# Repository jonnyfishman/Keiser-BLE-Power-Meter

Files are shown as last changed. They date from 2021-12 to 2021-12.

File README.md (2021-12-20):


<h3 align="center">BLE Power Meter</h3>

  <p align="center">
    Do you have an exercise bike without bluetooth but would still like to use training platforms like Zwift, Rouvy and Training Peaks? Using the Adafruit Feather nRF52 you can.
    <br />

  </p>
</div>

<!-- TABLE OF CONTENTS -->
<details>
  <summary>Table of Contents</summary>
  <ol>
    <li>
      <a href="#about-the-project">About The Project</a>
    </li>
    <li>
      <a href="#getting-started">Getting Started</a>
      <ul>
        <li><a href="#prerequisites">Bill of Materials</a></li>
        <li><a href="#prerequisites">Wiring</a></li>
        <li><a href="#installation">Installation</a></li>
        <li><a href="#acknowledgments">Acknowledgments</a></li>        
      </ul>
    </li>
    <li><a href="#license">License</a></li>
  </ol>
</details>

<!-- ABOUT THE PROJECT -->
## About The Project

Most older exercise bikes lack modern bluetooth compatibility but do still have a readout of the power generated. Using the Adafruit Feather you can bridge this gap.

This project was designed for the Keiser M3 exercise bike specifically but could be adapted to various others.

Most older exercise bikes use pedal cadence to calculate the power which appears on the head unit. To keep it compact and the design below uses a hall effect sensor and a magnet on the pedal arm to calculate cadence but you could modify the bikes cadence sensor directly as an alternative.

It also uses an MPU6050 on the gear selector to detect changes and adjust the power output. Once calibrated it can be adjusted to replicate the changes in power seen on the exercise bike head unit.

<p align="right">(<a href="#top">back to top</a>)</p>

<!-- GETTING STARTED -->
## Getting Started

### Bill of Materials

* An [Adafruit Feather nRF52](https://www.adafruit.com/product/3406)
* MPU6050
* A low voltage unipolar hall effect sensor
* Lipo battery (optional)

### Wiring

Components are wired as follows.

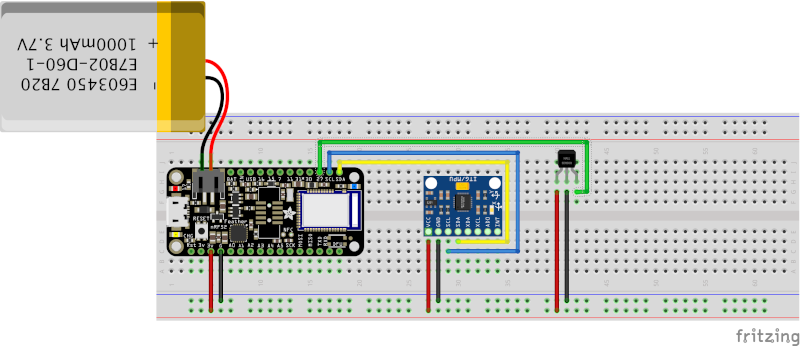
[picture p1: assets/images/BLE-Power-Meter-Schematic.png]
BLE Power Meter Fritzing


This can be soldered compactly as follows. **Notice the horizontal orientation of the MPU6050.**

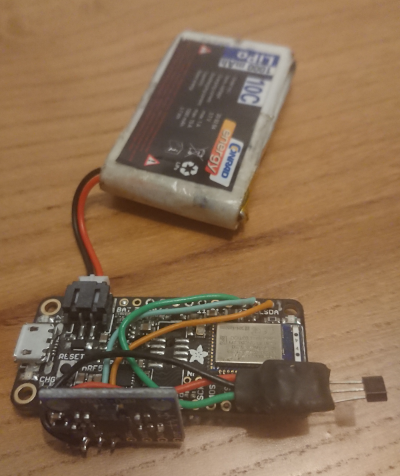
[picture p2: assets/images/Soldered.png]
Soldered Circuit


And temporarily mounted of the Keiser M3 with MPU6050 at the top.

Circuit Mounted

### Installation

1. Follow the instructions on the Adafruit site to connect the nRF52832 to Arduino IDE. [https://learn.adafruit.com/bluefruit-nrf52-feather-learning-guide](https://learn.adafruit.com/bluefruit-nrf52-feather-learning-guide)

2. Clone the repo
   ```sh
   git clone https://github.com/jonnyfishman/Keiser-BLE-Power-Meter.git
   ```
3. Open `BLE_Power/BLE_Power.ino` in the Arduino IDE (if you move the main `.ino` file make sure that all the included `.cpp` and `.h` files are in the same directory)

4. Edit the code if needed.

> By default debugging is disabled. To enable it remove the comments from the start of the file.

```ide
//#define DEBUG  
    BECOMES
#define DEBUG  
```

> Optionally adjust.

```ide
#define CALIBRATE_WAIT_MS   3000          // How long the sensor will initially wait for the low and high set points
#define HALL_EFFECT_SENSOR  27            // Where the hall effect sensor sense pin is connected
#define LED_PIN             LED_RED       // For visual reference using the onboard LED
#define TIMING_ERROR        10            // For the state engine timing. Increase data does not seem to be arriving
```

5. Flash the code to your board.

6. Connect to the training platform of your choice. When powered the device should show up as a power source.

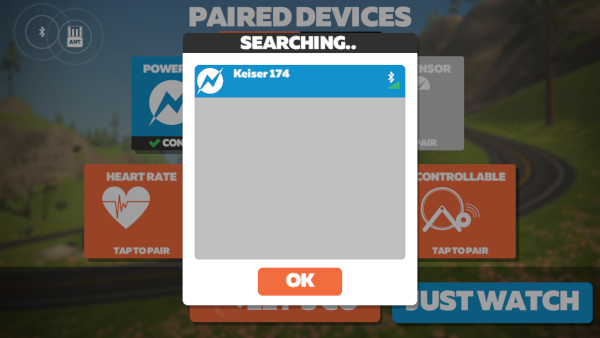
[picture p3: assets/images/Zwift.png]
Zwift Device Selection Screen


<p align="right">(<a href="#top">back to top</a>)</p>

## Roadmap

<ul>
  <li>Add CCCD callback for custom settings to detect if sending is required</li>
  <li>Update app and publish</li>
  <li>Explain gear selection code</li>
  <li>Explain how to map power from other exercise bikes</li>
  <li>Add BLE troubleshooting guide</li>
</ul>

<!-- LICENSE -->
## License

Distributed under the MIT License. See `LICENSE.txt` for more information.

<p align="right">(<a href="#top">back to top</a>)</p>

<!-- ACKNOWLEDGMENTS -->
## Acknowledgments

A lot of the inspiration and help with the bluetooth characteristics comes from Bruno Fernandez-Ruiz's Javascript power meter code. He has various other power meter projects if you are interested.

[https://github.com/olympum/ble-cycling-power](https://github.com/olympum/ble-cycling-power)

<p align="right">(<a href="#top">back to top</a>)</p>

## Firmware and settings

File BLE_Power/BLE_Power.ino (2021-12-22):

//#define DEBUG           
#ifdef DEBUG
  #define DEBUG_PRINT(x)        Serial.print(x)
  #define DEBUG_PRINTLN_HEX(x)  Serial.println(x,HEX)
  #define DEBUG_PRINTLN(x)      Serial.println(x)
#else
  #define DEBUG_PRINT(x)
  #define DEBUG_PRINTLN_HEX(x)
  #define DEBUG_PRINTLN(x) 
#endif 

#define CALIBRATE_WAIT_MS   3000          // How long the sensor will initially wait for the low and high set points
#define HALL_EFFECT_SENSOR  27            // Where the hall effect sensor sense pin is connected
#define LED_PIN             LED_RED       // For visual reference using the onboard LED
#define TIMING_ERROR        10            // For the state engine timing. Increase data does not seem to be arriving

// Main BLE stack
#include <bluefruit.h>

// MPU6050 Power Data
#include "Power.h"
CalculatePower calculatepower;

// Power Meter BLE services
#include "BLEService.h"
SetupGATT setupgatt;
BLENotify blenotify;

// Battery BLE service
#include "BatteryService.h"   
FeatherBattery featherbattery;

// Variables used in main loop
int cadence = 0;
unsigned long tick = 0;
unsigned long last_event_time = 0;
unsigned long total_revolutions = 0;
uint16_t event_time = 0;

void setup() {
  Serial.begin(115200);

  pinMode(HALL_EFFECT_SENSOR, INPUT);               // Setup hall effect sensor to detect cadence
  
  calculatepower.begin();                           // Setup MPU6050

  DEBUG_PRINTLN("\nSet gear max and min values");   // Configure set points
  
    digitalWrite(LED_PIN,HIGH);
    delay(CALIBRATE_WAIT_MS);
    calculatepower.setLowGear();
    digitalWrite(LED_PIN,LOW);
    delay(CALIBRATE_WAIT_MS);
    digitalWrite(LED_PIN,HIGH);
    delay(CALIBRATE_WAIT_MS);
    digitalWrite(LED_PIN,LOW);
    calculatepower.setHighGear();

  while ( !Serial ) delay(10);                      // for nrf52840 with native usb

  DEBUG_PRINTLN("Configuring the Cycle Power Service");
  setupgatt.Config();                             
  setupgatt.CyclePower();                         
  setupgatt.CycleSettings();  
  
  // Setup the advertising packet(s)
  DEBUG_PRINTLN("Setting up the advertising payload(s)");
  setupgatt.Advertising();

  DEBUG_PRINTLN("Advertising!");
}

void loop() {

  if ( setupgatt.get_connected() == true ) {                         // Only send values if the peripheral is connected

          // Get cadence information
          
          if ( digitalRead(HALL_EFFECT_SENSOR) == LOW ) {           // Detect a full revolution

            digitalWrite(LED_PIN,HIGH);                             // Trigger visual for revolution
                               
          unsigned long time_diff = millis() - last_event_time;     // Time difference since last rotation (not event time yet)
          last_event_time = millis();
          
          /* 
           *  time_diff = 1 revolution
           *  time_diff / time_diff = 1 revolution / time_diff                                       (gives revolution / ms)
           *  time_diff / time_diff * 60000 (ms in a minute) = 1 revolution * 60000 / time_diff      (gives rev / min)
           */
          cadence = 60000 / time_diff;  
          
          // Add to cumulative value
          total_revolutions++;                                       

          /*
           *  In spec - Unit is in seconds with a resolution of 1/2048 
           *  so millis is multiplied by 1000 (to get seconds) and divided by 1024
           *  Spec accepts a 16bit value for the time so anything higher than 2^16 (65536) needs to rollover using modulus
           */
          event_time = ( millis() * 1000 / 1024 ) % 65536;  

            // Prevent getting repeated values for the same revolution i.e. if cadence sensor stops in front of the hall effect sensor
            while ( digitalRead(HALL_EFFECT_SENSOR) == LOW ) {    
              delay(5);
              //wait until event finishes
            }
            
            digitalWrite(LED_PIN,LOW);                            // Trigger end of visual
            
                    
          }
          else if ( millis() - last_event_time > 6000 ) {         // Return cadence to zero if the pedalling is stopped for 6 seconds
              cadence = 0;          
          }   // End of digitalRead(HALL_EFFECT_SENSOR) == LOW loop

        /* 
         *  Control the timing of the following events using millis() to detect every half second
         *  If sensor information is being missed then increase the TIMING ERROR
         *  Using old_tick ensure that each block only sends once
         *  If power meter response is sluggish, adjust these values to update the information more often
         */
        unsigned long old_tick = tick;        
        if (millis()%500 <= TIMING_ERROR) {               
          tick++;
        }

        // Send sensor information     
        if ( tick != old_tick && tick%2 == 0 ) {              // Send power data every second half second
            uint16_t power = calculatepower.CadenceToPower(cadence);      // Get power from cadence
            blenotify.CyclePower(power, total_revolutions, event_time );  
            
            DEBUG_PRINT("Cadence: " );DEBUG_PRINT(cadence);DEBUG_PRINT(" Power: " );DEBUG_PRINT(power);DEBUG_PRINT(" Total Revs: ");DEBUG_PRINT(total_revolutions);DEBUG_PRINT(" Event Time: ");DEBUG_PRINTLN(event_time);        
        }
        
        if ( tick != old_tick && tick%2 == 0 ) {                   // Send settings information every second tick i.e. 1s
            calculatepower.update();                  // Update gear and angle            
            uint16_t power = calculatepower.CadenceToPower(cadence);      // Get power from cadence
            int battery_percent = featherbattery.getPercent();            // Get battery value
            blenotify.CycleSettings( calculatepower.getGear(), calculatepower.getAngle(), cadence, battery_percent );
            
            DEBUG_PRINT("Gear: " );DEBUG_PRINT(calculatepower.getGear());DEBUG_PRINT(" Angle: ");DEBUG_PRINT(calculatepower.getAngle());DEBUG_PRINT(" Cadence: ");DEBUG_PRINTLN(cadence);
            
            // Check for a command from the app
            int command = setupgatt.get_command();
              if ( command > 0 ) {
                    
                    switch(command){                                           
                        case 'a': 
                          calculatepower.setLowGear();
                          
                          break;
                        case 'b': 
                          calculatepower.setHighGear();
                          
                          break;                          
                        default:                                                // Assume gear is somehow out of bounds 
                          
                          break;
                        }
                        
                     setupgatt.clear_command();
              }
            } 
            
            if ( tick != old_tick && tick%120 == 0 ) {                  // Send battery value every minute
                int battery_percent = featherbattery.getPercent();            // Get battery value
                blenotify.Battery( battery_percent );
                DEBUG_PRINT("Batery: ");DEBUG_PRINTLN(battery_percent);
            } 
         
          
          
  } // End of setupgatt.get_connected() == true loop
  
} 

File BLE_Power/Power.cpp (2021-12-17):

#include <Arduino.h>
#include "Power.h"

long minVal, maxVal;
float angle;

float X_accel_offset, Y_accel_offset, Z_accel_offset;

extern int gear_threshhold;
extern int gear;

void CalculatePower::begin() {                         
  Wire.begin(); 
  Wire.beginTransmission(MPU6050_ADDR);               // Contact MPU6050
  Wire.write(MPU6050_SIGNAL_PATH_RESET_REGISTER);     // Power management register
  Wire.write(0x01 );                                  // Send reset code
  Wire.endTransmission(false); 
  Wire.write(MPU6050_ACCEL_CONFIG_REGISTER);          // Accel config register
  Wire.write(0x18);                                   // Set range to +-16G to smooth motion somewhat
  Wire.endTransmission(true); 

  this->getOffsets();                                 // Reduce error (https://www.digikey.co.uk/en/articles/using-an-accelerometer-for-inclination-sensing)
}

void CalculatePower::getOffsets() {                         
  float accumulated_raw[3] = {0,0,0};                 
  
  for(int i = 0; i < OFFSET_LOOP; i++){
    this->readRaw();
    accumulated_raw[0] += X_accel;
    accumulated_raw[1] += Y_accel;
    accumulated_raw[2] += Z_accel;
    delay(1);                                         // Short delay to get different values
  }

  // Get average position
  X_accel_offset = X_accel / OFFSET_LOOP;
  Y_accel_offset = Y_accel / OFFSET_LOOP;
  Z_accel_offset = Z_accel / OFFSET_LOOP;
}

int CalculatePower::setGearLimits(int pointer) {                         
  
  int accumulated_angles = 0;                         // This does the same as getOffsets but with the angle 
  
  for(int i = 0; i < LIMIT_LOOP; i++){
    this->update();
    accumulated_angles += angle;
    delay(1); 
  }

  return limits[pointer] = accumulated_angles / LIMIT_LOOP;
}

void CalculatePower::readRaw() {    
  Wire.beginTransmission(MPU6050_ADDR); 
  
  Wire.write(MPU6050_ACCEL_OUT);                      // Start receiving accelerator values
  Wire.endTransmission(false);                        // Send stop message but remain in control
  Wire.requestFrom(MPU6050_ADDR,6,true);              // Request X,Y and Z data 

  int16_t rawData[3];       
  
  for(int i=0;i<3;i++){
    rawData[i] =  Wire.read()<<8|Wire.read();         // Get rawdata and merge H and L bit
  }

  Wire.endTransmission(true);                         
  
  X_accel =  (float)rawData[0] / 2048.0;              // Convert raw data +-16G needs / 2048
  Y_accel =  (float)rawData[1] / 2048.0;
  Z_accel =  (float)rawData[2] / 2048.0;

  
}

void CalculatePower::update() {
  this->readRaw();
  
    // Calculations from https://www.digikey.co.uk/en/articles/using-an-accelerometer-for-inclination-sensing
    // This calc takes into account the offset error. readRaw does not    
    
    // Range is -90 to +90 because of the tan function being used
    // To get range -180 to 180 Z component is included (https://www.i2cdevlib.com/forums/topic/24-roll-and-pitch-angles-ranges/?do=findComment&comment=843)
    // Get angle and convert to degs * 10 for greater resolution in map function (time by 572.9578 not 57.29578)
  int z_component = (Z_accel-Z_accel_offset) > 1 ? 1 : -1; 
  angle = atan2( (Y_accel-Y_accel_offset), z_component * sqrt( ((X_accel-X_accel_offset)*(X_accel-X_accel_offset)) + ((Z_accel-Z_accel_offset)*(Z_accel-Z_accel_offset)) ) ) * 572.9578; 
  
    // Map angle to a gear
  int tempGear = map( angle, limits[0], limits[1], LOWEST_GEAR, HIGHEST_GEAR);
  tempGear < LOWEST_GEAR ? tempGear = LOWEST_GEAR : tempGear = tempGear;          // Prevent gear going higher or lower than limits
  tempGear > HIGHEST_GEAR ? tempGear = HIGHEST_GEAR: tempGear = tempGear;
            
  gear = tempGear;
  
}

int CalculatePower::CadenceToPower(int cadence) {

  int power;

  if ( cadence > MAX_CADENCE || cadence < MIN_CADENCE ) { // Disregard and cadence outside of those mapped into PowerData
    power = 0;
    return power;
  }

  switch(gear){                                           // Call correct array for result. This is quicker than using a formula
  case 8: 
    power = pgm_read_word( &GEAR8[cadence] );
    break;
  case 9: 
    power = pgm_read_word( &GEAR9[cadence] );
    break;
  case 10: 
    power = pgm_read_word( &GEAR10[cadence] );
    break;
  case 11: 
    power = pgm_read_word( &GEAR11[cadence] );
    break;
  case 12: 
    power = pgm_read_word( &GEAR12[cadence] );
    break;
  case 13: 
    power = pgm_read_word( &GEAR13[cadence] );
    break;
  case 14: 
    power = pgm_read_word( &GEAR14[cadence] );
    break;
  case 15: 
    power = pgm_read_word( &GEAR15[cadence] );
    break;
  case 16: 
    power = pgm_read_word( &GEAR16[cadence] );
    break;                           
  default:                                                // Assume gear is somehow out of bounds 
    power = 0;
    break;
  }

  return power;
  
}

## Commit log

2021-12-13 Added files for the Readme
    [Keiser.xlsx]
2021-12-17 Major code revision
    Fixed minor bugs and added comments throughout
    [BLE_Power.ino, BatteryService.cpp, BatteryService.h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]
2021-12-20 Updated images
    [BLE Power Meter Schematic.fzz]
